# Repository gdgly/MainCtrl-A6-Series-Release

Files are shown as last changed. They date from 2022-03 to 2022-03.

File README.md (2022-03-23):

# 机器人主控制器A6 Series  
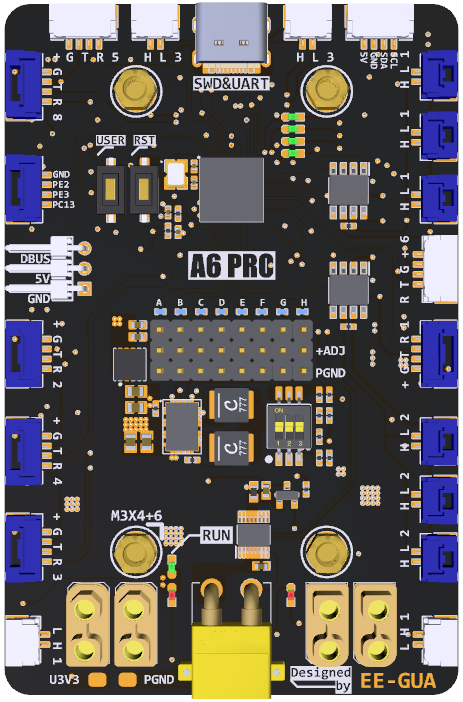
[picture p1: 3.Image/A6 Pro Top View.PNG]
顶视图
  

## 版本差异  
- 设计理念变更：主控放置点由机器人云台改为机器人底盘  
- 设计理念变更：主控分为基础版、升级版  
- 设计方案变更：板层由两层改为四层  
- 设计方案变更：防止插接件松动，SWD及UART调试集成为Type-C接口，线序自定  

|MODEL|基础版A6|升级版A6 Pro|
|:---:|:---:|:---:|
|MCU|STM32F405RGT6|STM32F767VIH6|
|FREQUENCY|MAX 168MHz|MAX 216MHz|
|FLASH SIZE|1024kB|2048kB|
|RAM TOTAL|192kB|512kB|
|SWD|USBType-C|USBType-C|
|IIC|1|2|
|CAN 2.0B|2|3|
|PWM|1|8|
|LED|2|4|
|UART|6|8|
|USER KEY|√|√|
|MICRO SD|×|√|
|ADJ OUTPUT|×|√|
|POWER MONITOR|×|√|
## 电气参数  
|PARA|DSCP|MIN|TYP|MAX|UNITS|
|:---:|:---:|:---:|:---:|:---:|:---:|
|Vin|Power Input Voltage|12.0|24.0|28.0|V|
|Iin|Power Input Current|||15.0|A|
|Vout1/2|Output Voltage 1/2|Vin-0.1|Vin|Vin|V|
|Iout1/2|Output Current 1/2|||15.0|A|
|Vadj|Adjust Output Voltage|5.0|5.0|12.2|V|
|Iadj|Adjust Output Current|||8.0|A|
|Iout(5V)|Output Current in 5V|||3.0|A|
|Iout(3V3)|Output Current in 3V3|||1.5|A|

These PARA only fit module A6 Pro.  
## 辅助模块相关 
- __[调试下载器（开发中）](https://github.com/EE-Gua/Debugger-Insight)__  
- __[OLED显示器（开发中）](https://github.com/EE-Gua/Screen-Spark)__  
- __[电源拓展板](https://github.com/EE-Gua/Power-Center)__  
## 资料相关 
- __[HI22X系列IMU资料](https://www.hipnuc.com/mkdocs_cn/site/imu_download/)__  
- __[Readme说明文档](https://github.com/EE-Gua/MainControl-A6-Series/tree/main/5.Readme)__  
## 注意事项 
*近年来现货元器件货源极其不稳定，TB购买的芯片很多都是翻新、假货*  
*如需更换元器件请从正规代理商渠道购买！！！*  
*本项目仅用作学习交流，请遵循相关开源协议！*

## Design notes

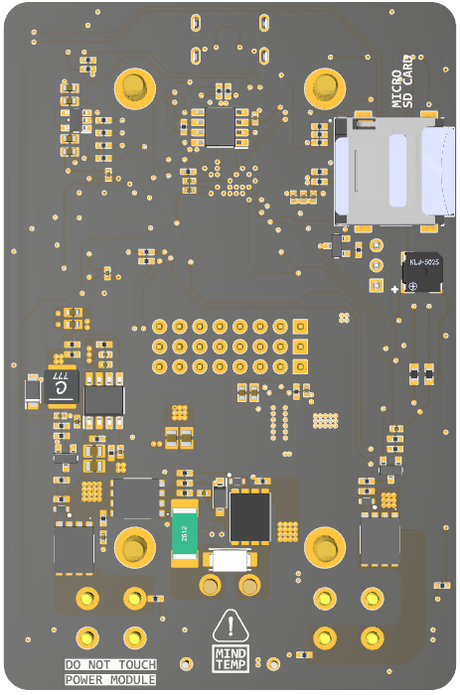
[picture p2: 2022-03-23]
3.Image/A6 Pro Bottom View.PNG

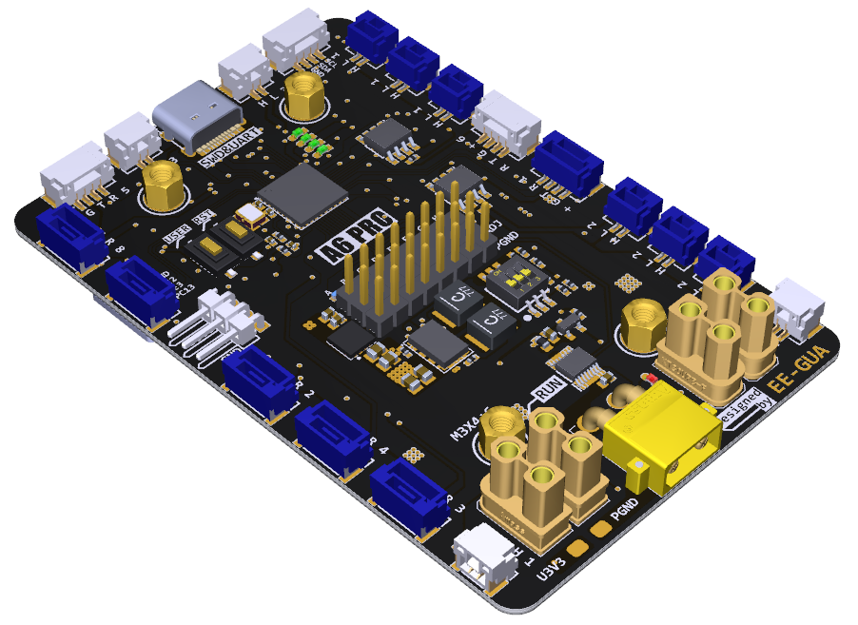
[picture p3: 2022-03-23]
3.Image/A6 Pro Default View.PNG

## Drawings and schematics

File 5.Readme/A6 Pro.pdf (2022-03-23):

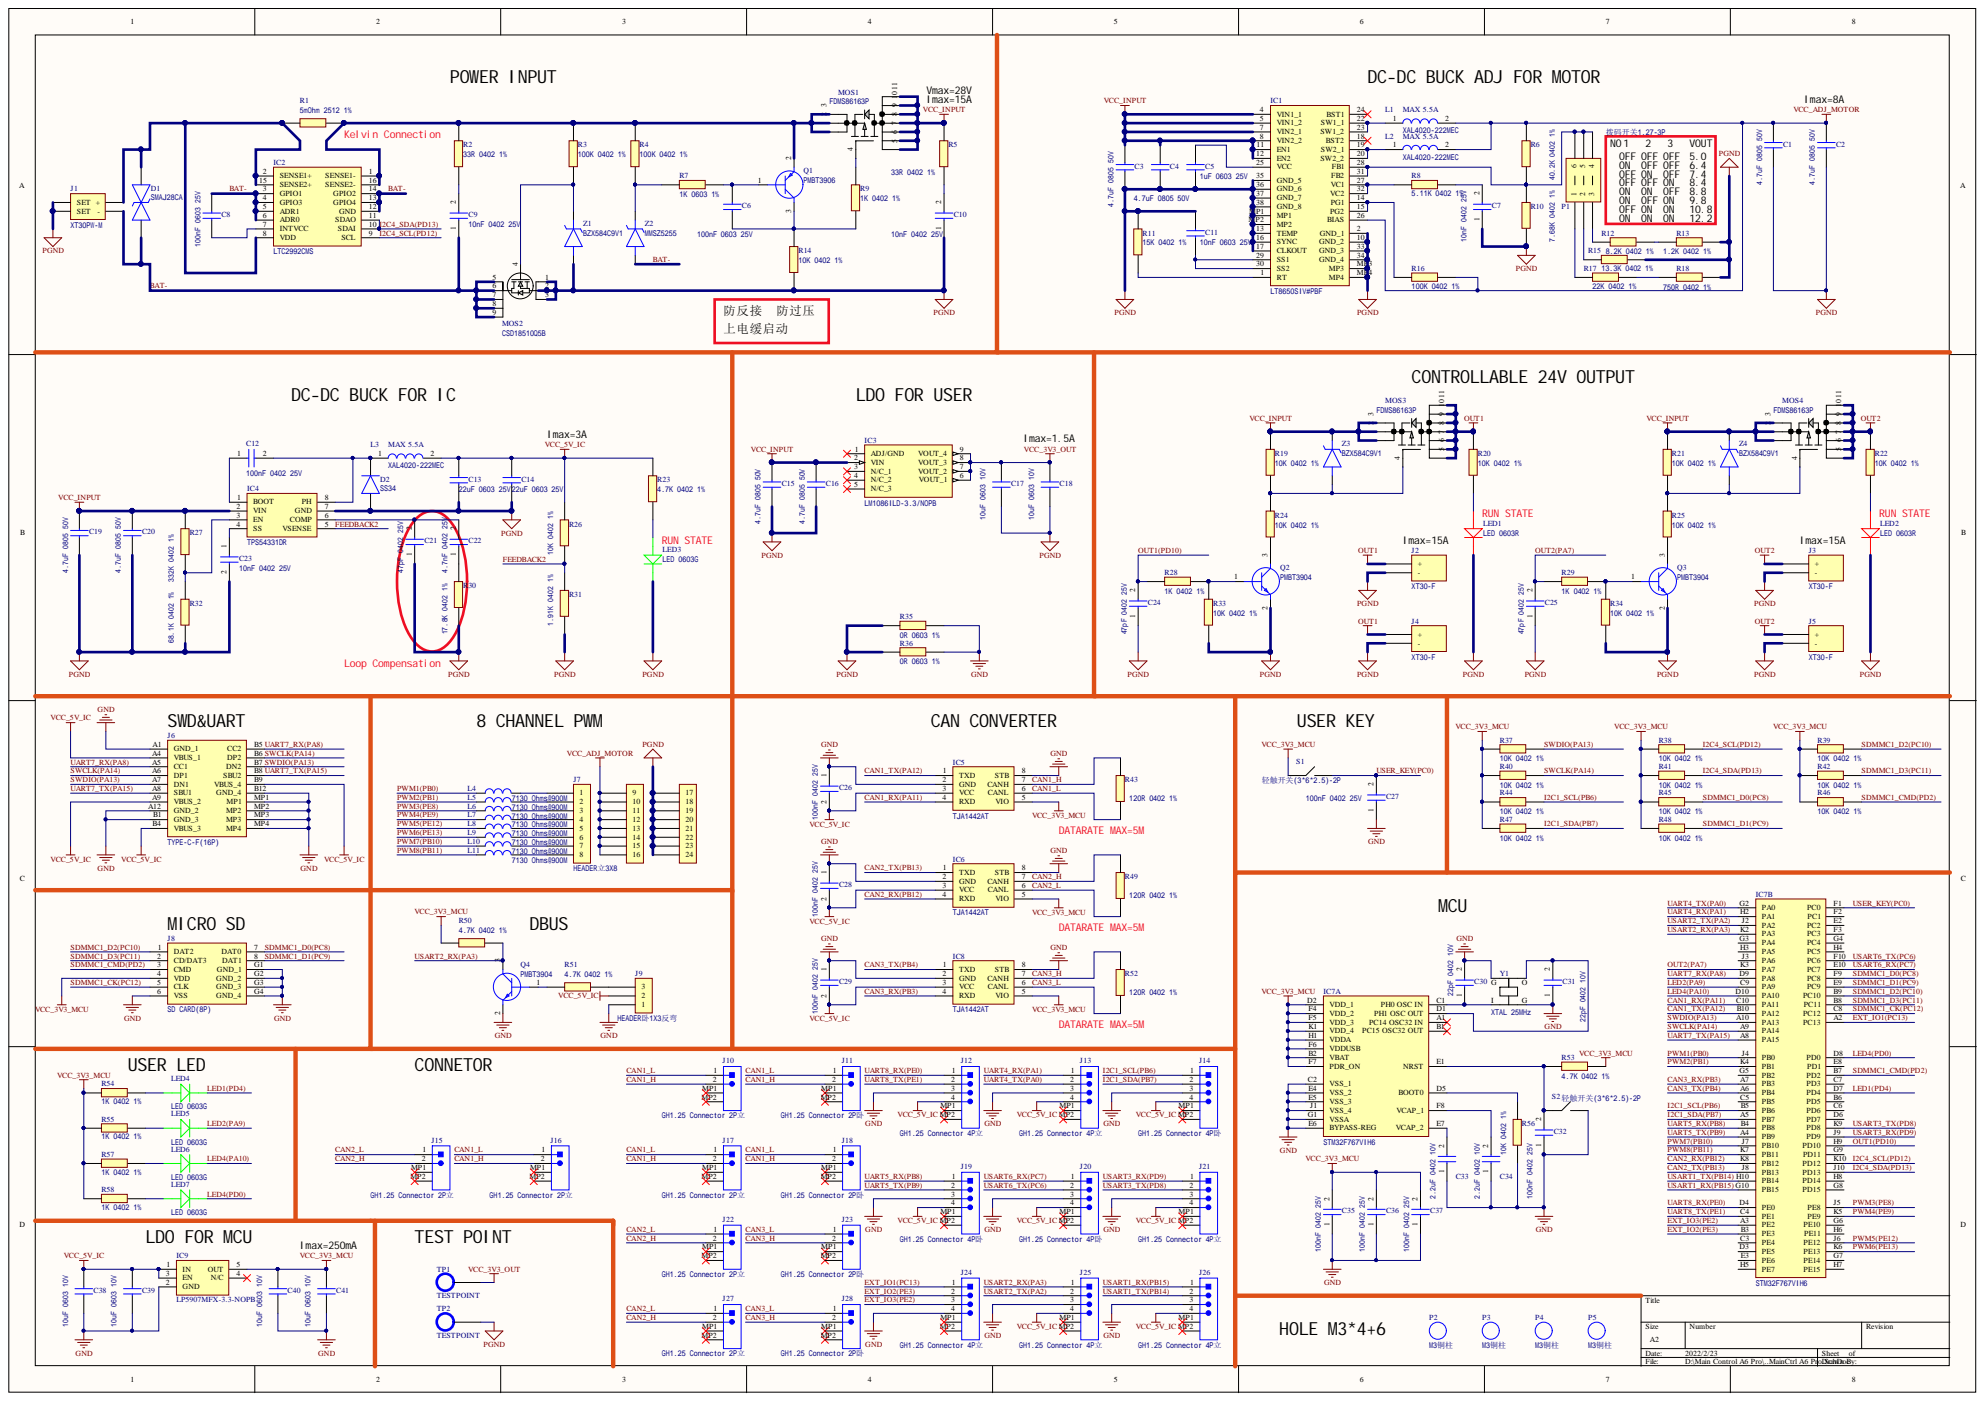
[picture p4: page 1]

DC-DC BUCK ADJ FOR MOTOR

拨码开关 .27-3P
OFF OFF OFF
ON OFF OFF OFF ON OFF OFF OFF ON ON ON OFF ON OFF ON OFF ON ON ON ON ON

DC-DC BUCK FOR IC

EN 3
SS 4 | Loop Compensation

Date: 2022/2/23 | Sheet of
File: D:\Main Control A6 Pro\..MainCtrl A6 ProD.SrcawhDon Bc y:

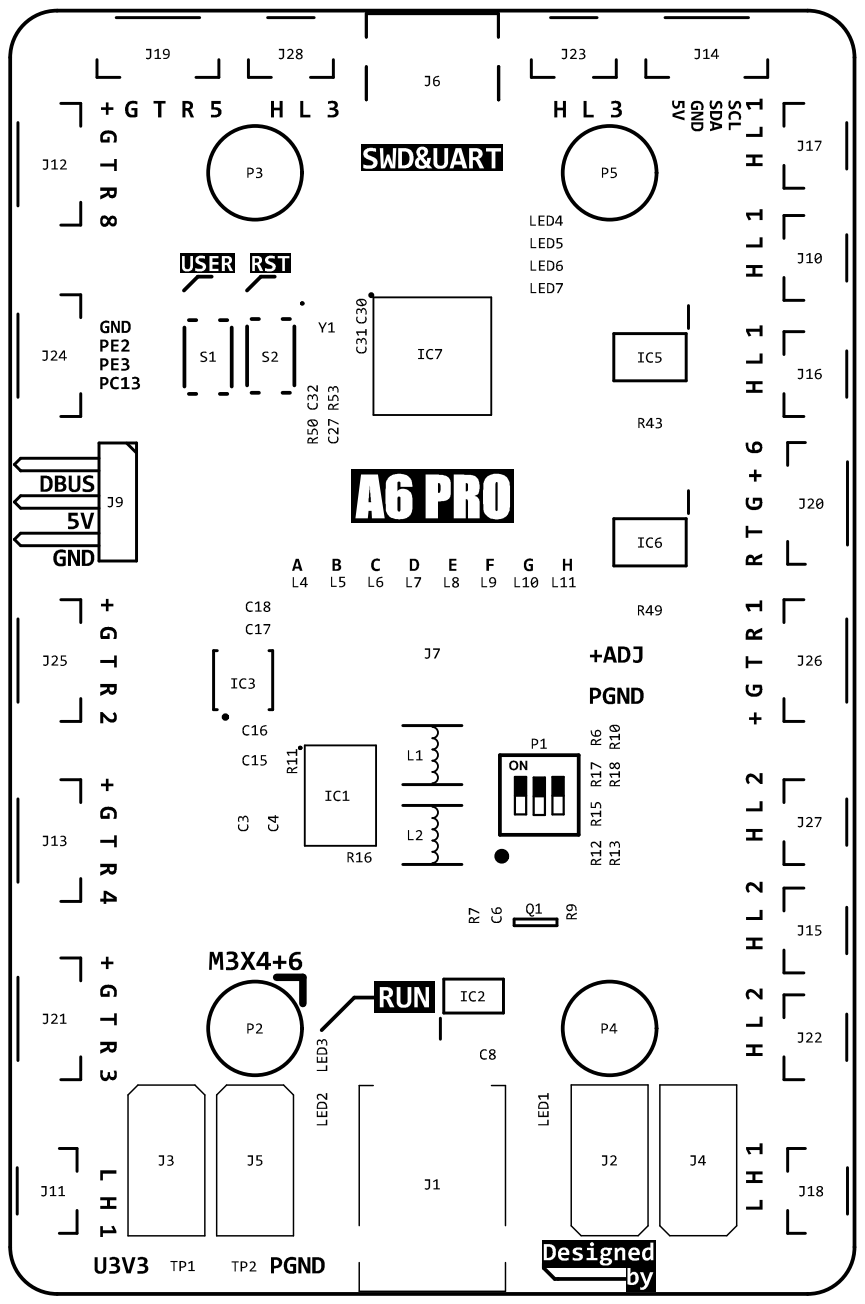
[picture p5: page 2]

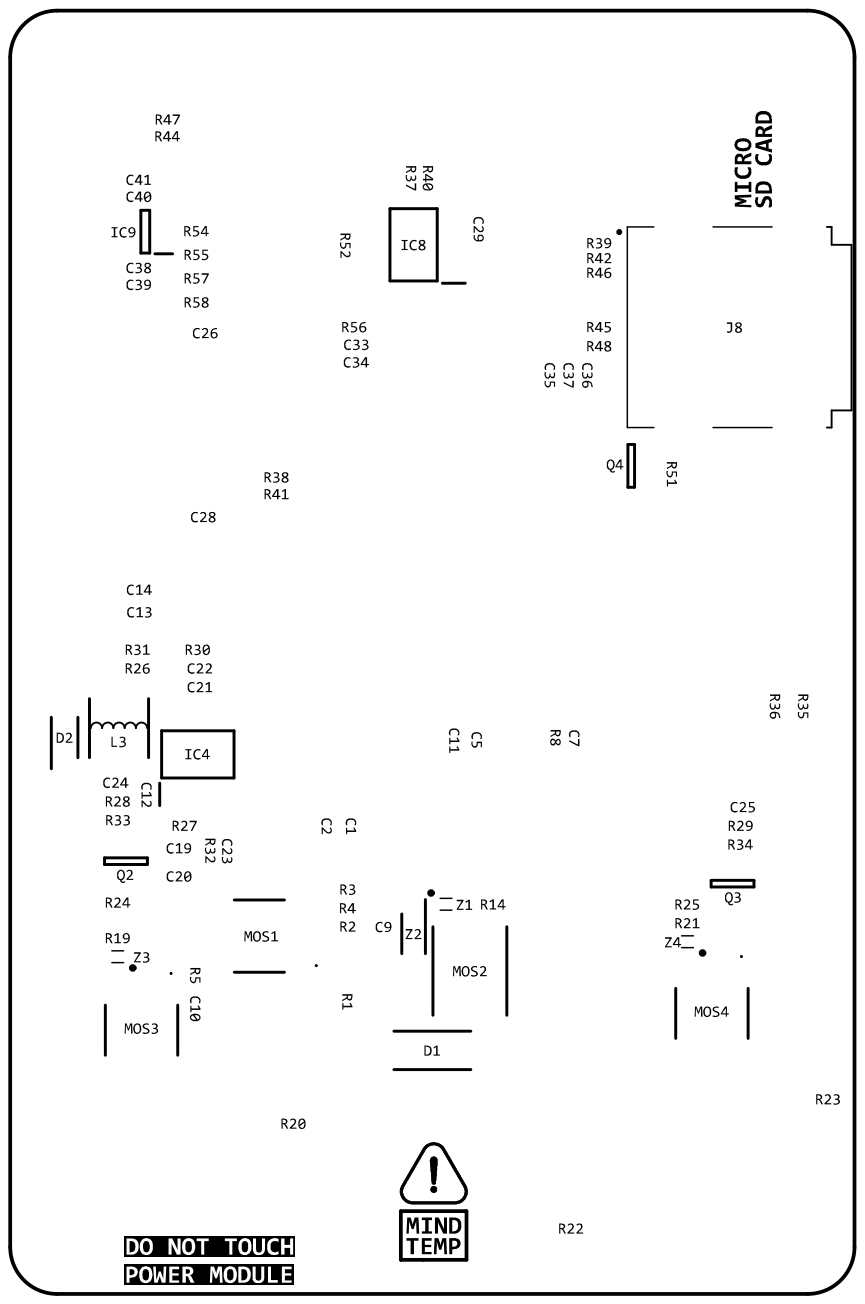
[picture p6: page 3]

Comment | Description | Designator | Footprint | Quantity
4.7uF 0805 50V | Capacitor | C1, C2, C3, C4, C15, C16, C19, C20 | C0805 | 8
1uF 0603 25V | Capacitor | C5 | C0603 | 1
100nF 0603 25V | Capacitor | C6, C8 | C0603 | 2
10nF 0402 25V | Capacitor | C7, C9, C10, C23 | C0402 | 4
10nF 0603 25V | Capacitor | C11 | C0603 | 1
100nF 0402 25V | Capacitor | C12, C26, C27, C28, C29, C32, C35, C36, C37 | C0402 | 9
22uF 0603 25V | Capacitor | C13, C14 | C0603 | 2
10uF 0603 10V | Capacitor | C17, C18, C38, C39, C40, C41 | C0603 | 6
47pF 0402 25V | Capacitor | C21, C24, C25 | C0402 | 3
4.7nF 0402 25V | Capacitor | C22 | C0402 | 1
22pF 0402 10V | Capacitor | C30, C31 | C0402 | 2
2.2uF 0402 10V | Capacitor | C33, C34 | C0402 | 2
SMAJ28CA | TVS Diode (Bi-directional) | D1 | SMAJ28CA | 1
SS34 | Diode | D2 | SS34 | 1
LT8650SIV#PBF | Integrated Circuit | IC1 | LT8650SEV#PBF | 1
LTC2992CMS | Integrated Circuit | IC2 | LTC2992CMS | 1
LM1086ILD-3.3/NOPB | Integrated Circuit | IC3 | LM1086ILD-3.3 | 1
TPS54331DR | Integrated Circuit | IC4 | TPS54331DR | 1
TJA1442AT | Integrated Circuit | IC5, IC6, IC8 | TJA1442AT | 3
STM32F767VIH6 | Integrated Circuit | IC7 | STM32F767VIH6 | 1
LP5907MFX-3.3-NOPB | Integrated Circuit | IC9 | LP5907MFX-3.3 | 1
XT30PW-M | Connector | J1 | XT30PW-M | 1
XT30-F | Connector | J2, J3, J4, J5 | XT30-F | 4
TYPE-C-F(16P) | Connector | J6 | TYPE-C-F(16P) | 1
HEADER 3X8 立 | Header | J7 | Header 3X8 立 | 1
SD CARD(8P) | Connector | J8 | SD CARD(8P) | 1
HEADER 1X3 卧 反 弯 | Header | J9 | Header 1X3 卧 反 弯 | 1
GH1.25 立 Connector 2P | GH1.25 Connector | J10, J15, J16, J17, J22, J27 | GH1.25 2P 立 | 6
GH1.25 Connector 2P 卧 | GH1.25 Connector | J11, J18, J23, J28 | GH1.25 2P 卧 | 4
GH1.25 立 Connector 4P | GH1.25 Connector | J12, J13, J21, J24, J25, J26 | GH1.25 4P 立 | 6
GH1.25 卧 Connector 4P | GH1.25 Connector | J14, J19, J20 | GH1.25 4P 卧 | 3
XAL4020-222MEC | Inductor | L1, L2, L3 | XAL4020 | 3
7130 Ohms@900M | Inductor 901XJR | L4, L5, L6, L7, L8, L9, L10, L11 | 0402DF | 8
LED 0603R | LED Red | LED1, LED2 | LED 0603R | 2
LED 0603G | LED Green | LED3, LED4, LED5, LED6, LED7 | LED 0603G | 5
FDMS86163P | MOSFET P-ch | MOS1, MOS3, MOS4 | FDMS86163P | 3
CSD18510Q5B | MOSFET N-ch | MOS2 | CSD18510Q5B | 1
拨码开关 1.27-3P | Switch | P1 | 拨码开关 1.27-3P | 1
M3 铜柱 | Hole M3X4+6 | P2, P3, P4, P5 | M3x4+6 铜柱 | 4
PMBT3906 | Transistor BJT PNP | Q1 | PMBT3906 | 1
PMBT3904 | Transistor BJT NPN | Q2, Q3, Q4 | PMBT3904 | 3
5mOhm 2512 1% | Resistor | R1 | R2512 | 1
33R 0402 1% | Resistor | R2, R5 | R0402 | 2
100K 0402 1% | Resistor | R3, R4, R16 | R0402 | 3
40.2K 0402 1% | Resistor | R6 | R0402 | 1
1K 0603 1% | Resistor | R7 | R0603 | 1
5.11K 0402 1% | Resistor | R8 | R0402 | 1
1K 0402 1% | Resistor | R9, R28, R29, R54, R55, R57, R58 | R0402 | 7
7.68K 0402 1% | Resistor | R10 | R0402 | 1
15K 0402 1% | Resistor | R11 | R0402 | 1
8.2K 0402 1% | Resistor | R12 | R0402 | 1
1.2K 0402 1% | Resistor | R13 | R0402 | 1
10K 0402 1% | Resistor | R14, R19, R20, R21, R22, R24, R25, R26, R33, R34, R37, R38, R39, R40, R41, R42, R44, R45, R46, R47, R48, R56 | R0402 | 22
13.3K 0402 1% | Resistor | R15 | R0402 | 1
22K 0402 1% | Resistor | R17 | R0402 | 1
750R 0402 1% | Resistor | R18 | R0402 | 1
4.7K 0402 1% | Resistor | R23, R50, R51, R53 | R0402 | 4
332K 0402 1% | Resistor | R27 | R0402 | 1
17.8K 0402 1% | Resistor | R30 | R0402 | 1
1.91K 0402 1% | Resistor | R31 | R0402 | 1
68.1K 0402 1% | Resistor | R32 | R0402 | 1
0R 0603 1% | Resistor | R35, R36 | R0603 | 2
120R 0402 1% | Resistor | R43, R49, R52 | R0402 | 3
轻触开关 (3*6*2.5)-2P | Switch | S1, S2 | 轻触开关 (3*6*2.5)-2P | 2
TESTPOINT | TestPoint | TP1, TP2 | TESTPOINT | 2
XTAL 25MHz | Crystal or Oscillator | Y1 | XTAL25MHz 3225 | 1
BZX584C9V1 | Zener Diode | Z1, Z3, Z4 | BZX584C9V1 | 3
MMSZ5255 | Zener Diode | Z2 | MMSZ5255 | 1
